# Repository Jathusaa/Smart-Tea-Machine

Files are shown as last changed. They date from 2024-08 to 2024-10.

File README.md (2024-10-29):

# Smart Tea Machine

This project features a Smart Tea Machine designed to automate the tea-making process. The machine includes various advanced features to enhance user experience:

## Features

- **Automatic Water Dispensing:** Dispenses the right amount of water for each cup of tea.
- **Tea Bag Dipping:** Dips the tea bag into the water to ensure optimal brewing.
- **Sugar Dispensing:** Automatically dispenses sugar according to user preferences.
- **Temperature Check:** Monitors the water temperature to ensure the perfect brewing conditions.
- **User Card System:** Utilizes RFID technology to recognize user preferences and customize the tea-making process.
- **User-Friendly Interface:** Designed for easy operation, featuring clear instructions and feedback.
- **Sound Alerts:** Equipped with a buzzer to alert the user when the tea is ready.

## Project Files

This repository includes the following files:

- **Arduino Code:** The main code for controlling the Smart Tea Machine.
- **PCB Files:** Design files for the printed circuit board (PCB) used in the machine.
- **Project Report:** A comprehensive PDF report explaining the design, functionality, and components of the Smart Tea Machine.

## Contributors

Thanks to the following team members for their contributions to this project:

- **[Jathusaa Indrakumaran](https://github.com/yourusername)** 
- **[Anisa Matan](https://github.com/Anisa-M1)** 
- **[Vishwa Prajapati](https://github.com/vishwapraja)**

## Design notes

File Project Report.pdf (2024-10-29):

## Smart Tea Machine Design Project Report

### ECE 2242

### Anisa Matan, Jathusaa Indrakumaran, Vishwa Prajapati

### Dr. Raveendra Rao

### April 2024

## Declaration Statement

We, the undersigned members of the group, collectively affirm that this report titled “Smart

Tea Machine Design Project Report” is our own joint work except where specifically

referenced. We take full responsibility for its accuracy and completeness.

Anisa Matan, Jathusaa Indrakumaran, Vishwa Prajapati

Date: April 7, 2024

## Acknowledgments

The team would like to express many thanks to everyone who helped create the Smart

Tea Machine. Special thanks to the individuals at the Western Electronics Shop

including Ron Struke, Eugen Porter, Trent Steensma and Robert Barbeito. Additional

appreciation is extended to the TAs of our lab section, Asad Hammed and Mayur

Sawant, as well as Professor Lyudmil Marinov and Professor Raveendra Rao for their

valuable assistance and support throughout the project.

## Table of Contents

## List of tables and figures

Fig. 1. Go-No-Go Chart | 7
Fig. 2. Comparison of Various Tea Machine Models by Tartar | 10
Fig. 3. Initial Block Diagram | 13
Fig. 4. Sketch of Prototype 1 | 15
Fig. 5. Sketch of Prototype 2 | 16
Fig. 6. Sketch of Prototype 3 | 16
Fig. 7. Final Block Diagram | 17
Fig. 8. Final Sketch of Prototype 1 | 18
Fig. 9. Tinkercad Circuit | 19
Fig. 10. Pseudocode | 20
Fig. 11. PCB Schematic Design | 21
Fig. 12. PCB Board Design | 21
Fig. 13. Soldered PCB Front and Back View | 23
Fig. 14. Finished Prototype Front and Back View | 24
Fig. 15. Finished Prototype Top and Side View | 24
Table 1: Sensors and Actuators Initially Used | 12
Table 2: Decision Matrix | 15
Table 3: Summary of Code Functions | 20

Abstract

This report details the design process in creating an Arduino operated automated tea

machine. The goal of this design project was to create an accessible appliance to automate a

common manual process for both homeowners and customers to save them time, reduce costs

and improve their user experience. By researching automated tea making machines currently

on the market, user needs, and the tea steeping process, the team was able to develop various

prototype ideas and set design objectives. The objectives of the Smart Tea Machine were

creating a user-friendly interface, dispensing water, sugar and tea to the user, and sensing water

level and temperature of the water used for steeping. After brainstorming multiple prototypes

ideas, the final design was chosen by taking durability, simplicity, cleanability, portability and

versatility into consideration. The prototype chosen employed five sensors, and four actuators

to achieve the objectives. Servo motors and a push button was used to dispense water and while

a DC motor and a push button was used to dispense sugar packets. Another servo motor was

used to dispense a tea bag into a cup of water. An LCD was used to communicate with the user,

and a buzzer was employed to notify the user when the tea steeping process was finished. A

water level sensor, and temperature sensor were also incorporated into the machine.

Additionally, a motion sensor was used to turn on the LCD when the user approached the

machine. Lastly, an RFID was also utilised to allow the machine to be used in commercial

settings. After simulating the circuit using Tinkercad, a PCB was designed and tested. The PCB

created was fully functioning and integrated with the mechanical design of the machine. Major

challenges of designing the Smart Tea Machine include the implementation of the RFID and

the water dispensing mechanism. Future improvements include making the design more

versatile to accommodate for wider varieties of tea and improving the mechanisms used to

dispense various ingredients. In conclusion, the project was successful overall, and all design

objectives were achieved.

### 1. Introduction

Despite developments in both household and commercial appliances in the modern age,

homeowners and customers alike still require more accessible and automated appliances for

common manual processes to save time, reduce costs, and improve user experience. Many

processes that are still manually done have not yet been refined and been made accessible to a

wide variety of users. This design project aimed to automate one such process for both

customers and homeowners. After thorough research into various processes that could benefit

from automated refinement and taking into consideration project requirements, the tea making

process was decided upon by weighing pros and cons of all brainstormed ideas with the use of

a Go-No-Go Chart as seen in Figure 1 and the “Idea Development” section of the design

notebook listed in the appendices.

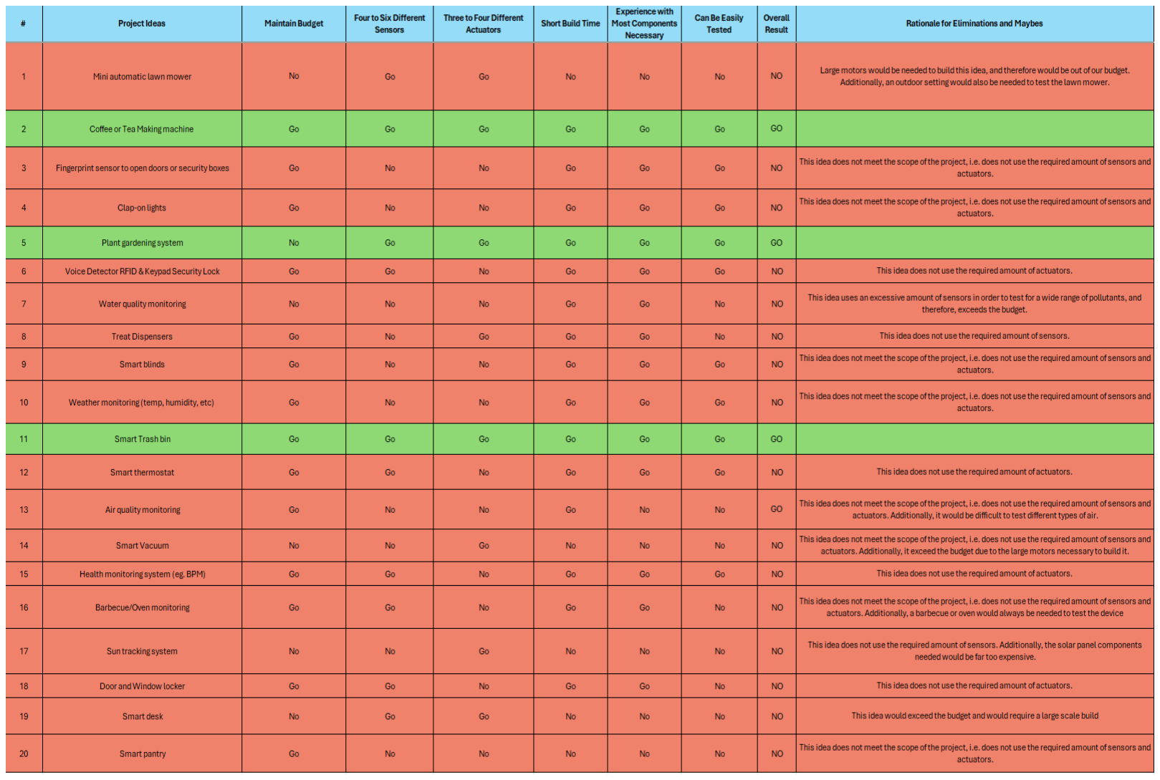
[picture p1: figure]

Fig. 1. Go-No-Go Chart Outlining if project constraints are met by various ideas

The tea making process could be improved for any individual by prioritizing

convenience and cost efficiency. While tea making machines are currently available on the

market, the lack of popularity is driven by high prices and lack of customization for creating

different types of tea. For example, the Breville One-Touch Tea Maker is one of the few tea

machines on the market that fully automates the tea making process in a similar fashion to a

coffee machine and retails for upwards of $200 [1]. Both tea enthusiasts and casual tea drinkers

need a higher quality and cheaper alternative to machines currently on the market. The tea

making process can also be difficult for individuals with disabilities due to the manual nature

of the process. Moreover, automating the process would facilitate making tea for individuals

with less experience as a machine would ensure consistency in temperature, water level, and

flavour. This design project aimed to specifically automate the process by:

- Creating an LCD user friendly interface
- Sensing temperature and water level of water required for tea making
- Dispensing water to the user
- Dispensing tea into water (either in the form of a tea bag or loose leaves)
- Dispensing sugar to the user

With these objectives in mind, a smart tea machine was created with the intention of

practical applications in various places like homes, offices, workplaces, restaurants, cafes,

healthcare facilities, events, and catering.

### 2. Literature Review

The literature review consisted of researching the tea steeping processes and various

tea making products currently on the market to better understand the needs of users. Tea

brewing refers to the general process in making tea, while steeping is the process of immersing

tea leaves in water. These findings aided in the development of initial prototypes and helping

to outline the objectives of the machine listed above.

A study done by Katherine Ann Tartar at MIT called “Simplifying Tea Steeping:

Design Innovation Driven by User Needs" succinctly summarizes the current automated tea

machine models, steeping methods and proposed alternatives [2]. Tartar conducted a survey of

235 individuals in the ages of 18 to 27 to determine their preferences in the tea making process.

She found that most user preferred tea bag over loose-leaf steeping due to the inherent

messiness of the process using a strainer. This insight prompted further research into the

differences between tea bag and loose-leaf steeping, revealing three key differences [3]:

- Tea bags are made from low quality, cheaper leaves that have been pulverized down

to tiny pieces, while loose leaves are whole, therefore, providing stronger flavour

- As the tea steeps, loose leaves are able to expand more and unravel to release flavour

while tea bags are tightly packed restricting flavour, but taking less time to brew

- Both tea bag and loose-leaf steeping require hot water, while loose leaves

additionally require a device to infuse the leaf flavour into the water, which can be

simple paper filters, tea pots, or strainers.

Tartar’s study also outlined the top features that the individuals surveyed would want

in a tea machine, which include water temperature testing, timing, removal of tea leaves,

portability, simplicity and cleanability. Another important piece of information from Tartar is

the comparison of various tea machine currently on the market and their short falls as seen in

the Figure 2. This comparison helped the team brainstorm prototypes that address the

shortcomings of current automated tea making options.

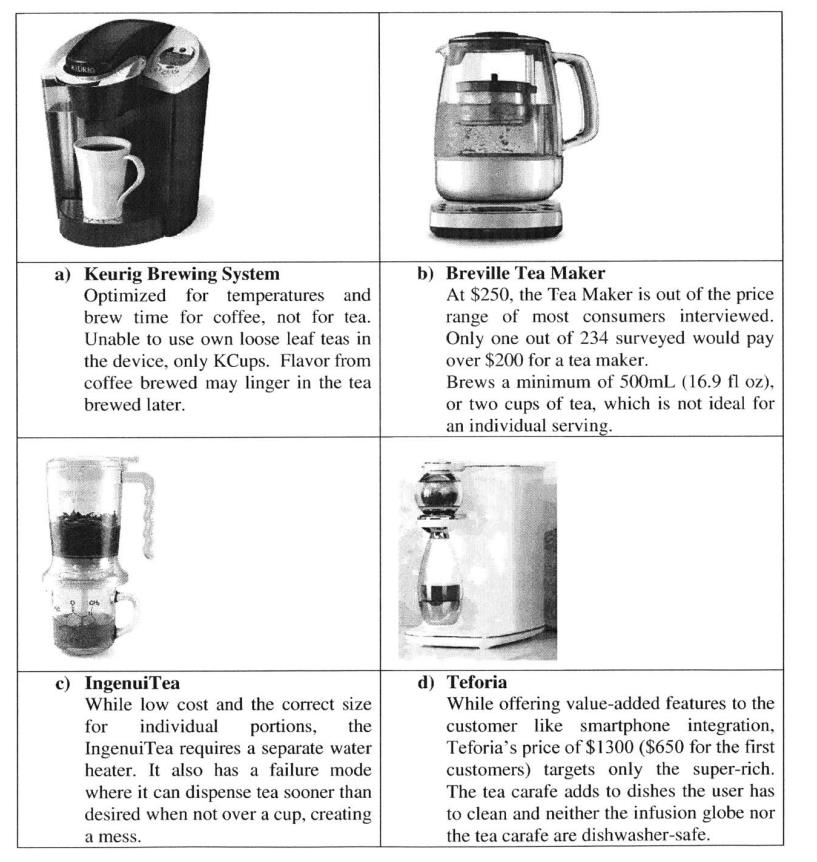
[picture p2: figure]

Fig. 2. A chart by Tartar highlighting various tea making machine currently on the market [2]

Lastly, research was done into cold vs hot water tea steeping to determine which would

be more effective in steeping the tea in the machine. According to research by Lantano et al.,

cold water steeping is most effective in extracting healthy molecules like antioxidants, while

hot steeping was faster but and extracted more flavour [4]. The study also considered an

emerging method which involved hot steeping and then adding ice to the tea. This information

was taken account when deciding the steeping method and water temperature used in the tea

making process.

### 3. Design Constraints and Standards

There were three major design constraints outlined at the beginning of the course:

- The final product must contain four to six sensors
- It must contain three to four actuators
- The software must work simultaneously with all components

Other design constraints determined by the team were pertaining to the budget, build

time, and testability. The team determined that the budget would not exceed $100 excluding

the $50 cost of the Arduino kit. The project selected also had to have a short build time allow

for debugging and successful function by the early April deadline. Furthermore, the project

selected would need to be tested easily. Projects that were eliminated were often difficult to

test due to their costly and time-inefficient nature. For example, a water quality monitoring

system that was considered in Figure 1 would require the purchasing of various unique sensors

and simulation of polluted water. Lastly, the team decided that the project chosen should not

require the use of too many (more than 3) components that the members did not have

experience working with.

### 4. Design

Based on the objectives of the machine, initially the team decided to use the

components summarized in table 1 below.

Table 1: Sensors and Actuators Initially used in the Smart Tea Machine

Type | Component | Signal | Quantity | Purpose
Sensor | Temperature sensor | Digital | 1 | Detects temperature of water being used to make tea
| Water level sensor | Analog | 1 | Detect how much water is needed to make tea
| Motion sensor | Digital | 1 | Detects when user wants to turn on machine
| Push button | Digital | 2 | Allows user to dispense water or sugar
| RTC | Digital | 1 | Times the process
| RFID | Digital | 1 | Allows user to earn discounts in a commercial setting
Actuator | Servo Motor | Digital | 2 | Dispenses water and tea bag in cup as well as sugar if it is uncontained
| Stepper Motor | Digital | 1 | To help dispense sugar if in the form of packets
| LCD | Digital | 1 | Displays instructions to user and narrates process
| Buzzer | Digital | 1 | Notifies user when tea making process is finished

The block diagram in Figure 3 was developed based on the table above which outlines

the inputs and outputs in relation to the Arduino.

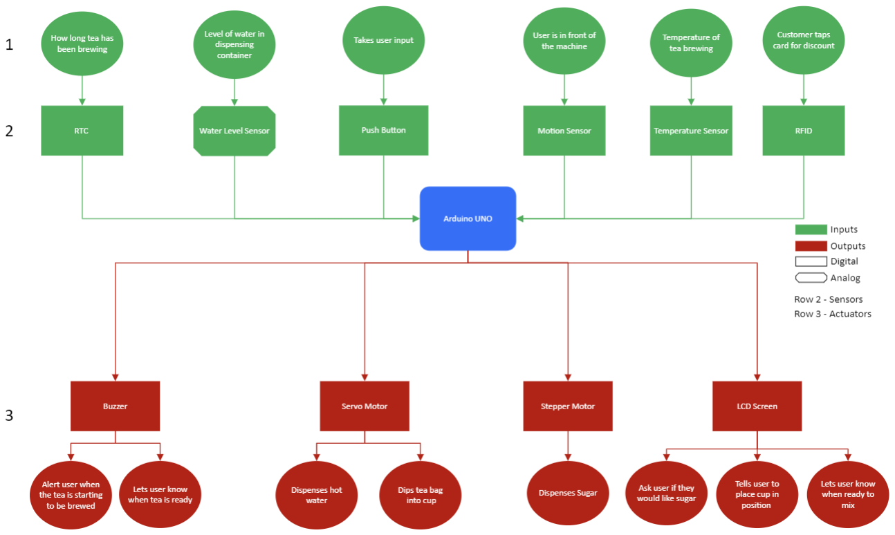
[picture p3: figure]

Fig. 3. The initial block diagram with RTC and stepper motor

Choosing a Prototype

Using the insights gained in the literature review, various prototypes ideas were generated

and decided upon using a decision matrix as seen in Table 2. The three prototype ideas were

developed, two of which used a tea bag while one used loose leaves. The team considered

creating prototype designs using both loose leaves and tea bags, however decided to focus on

tea bags as it would be more time-efficient for users. Additionally, it was decided that the

prototype were to be constructed out of recyclable materials to reduce costs. The attributes used

to rank the alternatives were based on the customer needs explored in the literature review and

the team’s priorities.

The metrics used to rank the prototype were as follows:

1. Simplicity: Is the prototype easy to operate, in other words, is it user friendly?
2. Cleanability: Does the prototype leave excessive waste for the user to clean up

afterwards?

3. Durability: Is the machine prone to damage or breaking?
4. Versatility: Does it allow the brewing of various types of tea?
5. Portability: Is the machine easy to move around?

The metrics had different weighting depending on how important they were to the team’s

objectives, as shown by the order in which they appear above. The weights were on a scale of

1 to 5. Each prototype idea was ranked on a scale of 1 to 10 in each of the categories and total

scores were added up.

There was also qualitative analysis that was considered in choosing each prototype.

Prototype 1, as seen in Figure 4, was the most compact and simple alternative but was lacking

full integration of the tea dipping mechanism into the machine. Additionally, dispensing

packets of sugar would be better suited for a commercial setting, while being less convenient

for a homeowner. Seen in Figure 5, Prototype 2 would be more ideal for tea enthusiasts rather

than casual tea drinkers due to the use of loose tea leaves. Furthermore, avid tea drinkers are

likely unconcerned with automated tea making, as they would be more willing to use traditional

methods to make quality tea. The team aimed to make the tea making process more accessible

for individuals who want to save time, so this eliminated the second prototype as an option.

Moreover, Prototype 2 would not be able to accommodate the amount of water needed to steep

the tea leaves. Lastly, Prototype 3, as seen in Figure 6, was more compact than Prototype 1 but

clustered many of components into a small area, making it non-user friendly and more difficult

to construct. There was also the use of the tube to direct the tea to the cup, making the design

prone to damage and leaking. Prototype 3 also use sugar that was uncontained, making it a

messy alternative. All prototypes ranked the same in the category of versatility as they could

only accommodate one type of tea steeping. Considering the result of the decision matrix and

qualitative factors, the team decided Prototype 1 was the best alternative as it ranked the highest

and met user needs the best.

Table 2: Decision Matrix Evaluating Prototypes

Metrics | Weight | Prototype 1 | Prototype 2 | Prototype 3
Simplicity | 5 | 8 | 5 | 6
Cleanability | 4 | 9 | 6 | 8
Durability | 3 | 7 | 6 | 4
Versatility | 2 | 5 | 5 | 5
Portability | 1 | 8 | 5 | 8
Total Score | | 115 | 82 | 92

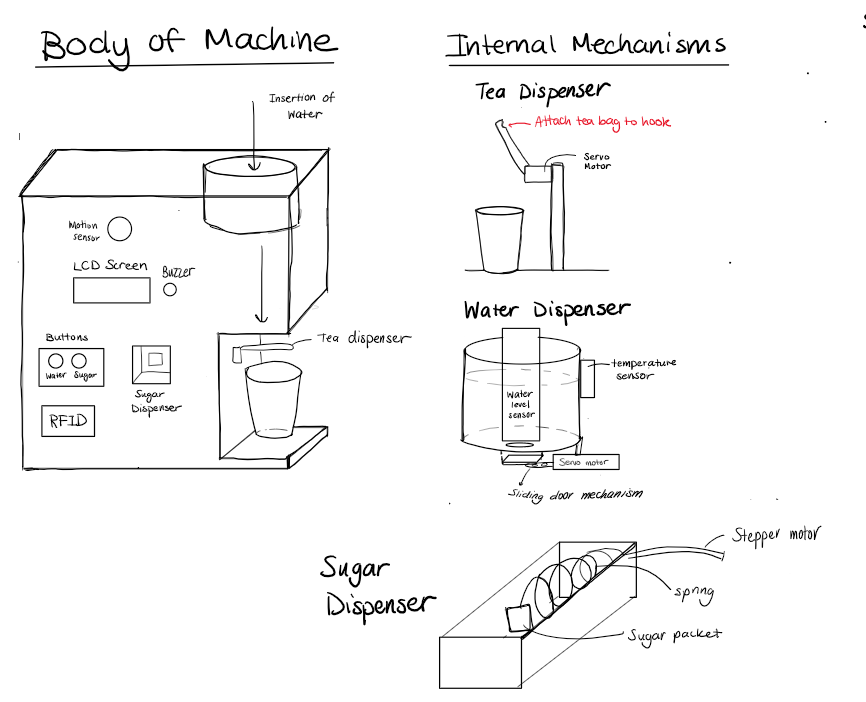
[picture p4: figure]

Fig. 4. Preliminary sketch of Prototype 1

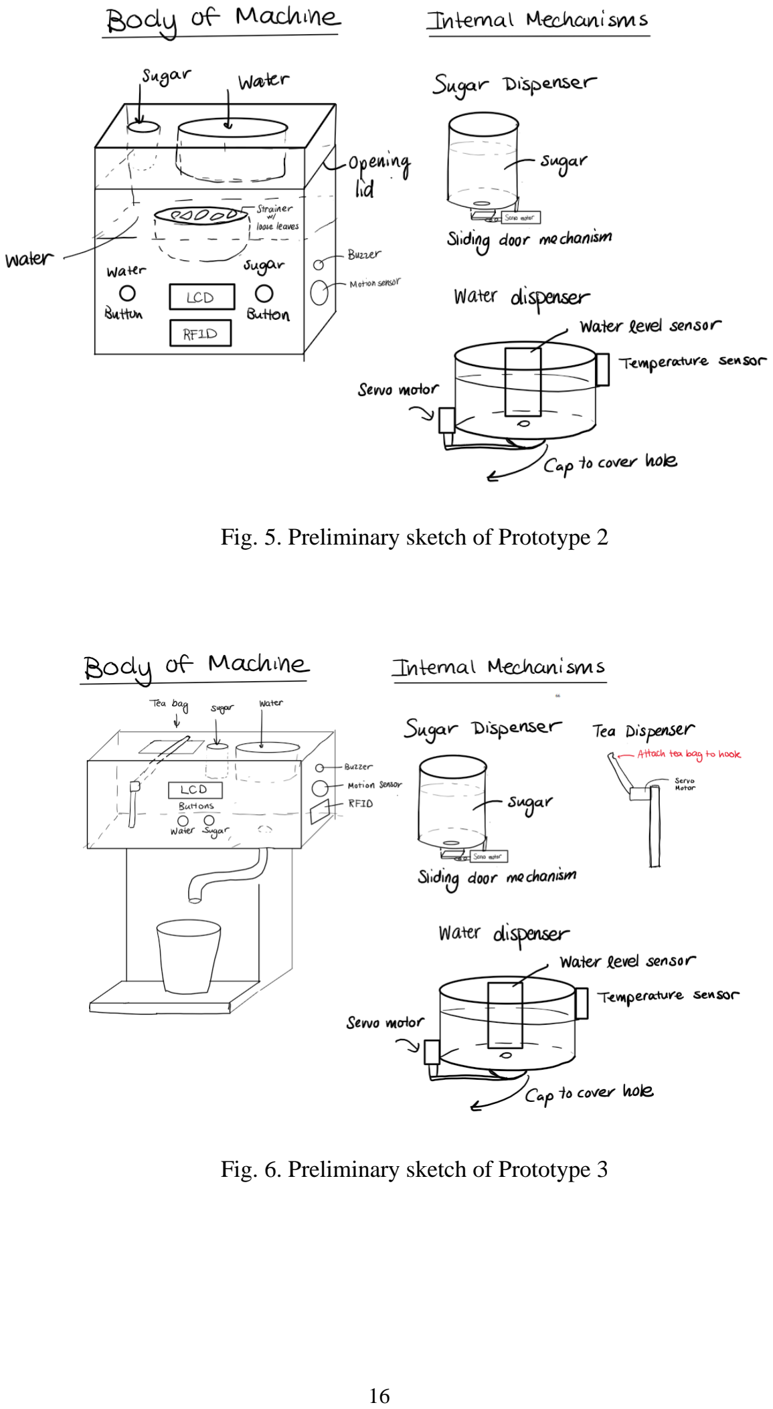
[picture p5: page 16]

Fig. 5. Preliminary sketch of Prototype 2

Fig. 6. Preliminary sketch of Prototype 3

Final Block Diagram and Sketch

After the final prototype was decided upon, the team was able to refine the initial block

diagram into the final one seen in Figure 7. The team decided to use a DC motor instead of

stepper motor due to previous experience with DC motors and access to one. Additionally, the

RTC component was eliminated as the Arduino has a built-in timing function that was simpler

to code and implement.

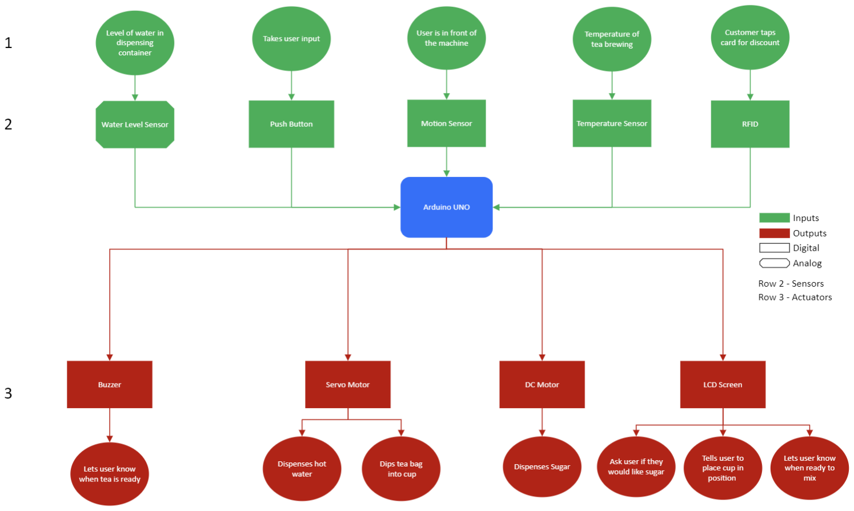
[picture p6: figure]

Fig. 7. Final block diagram showing all sensors and actuators that were used in final

prototype

A final sketch of the prototype was also created with dimensions and all final features,

as seen in Figure 8.

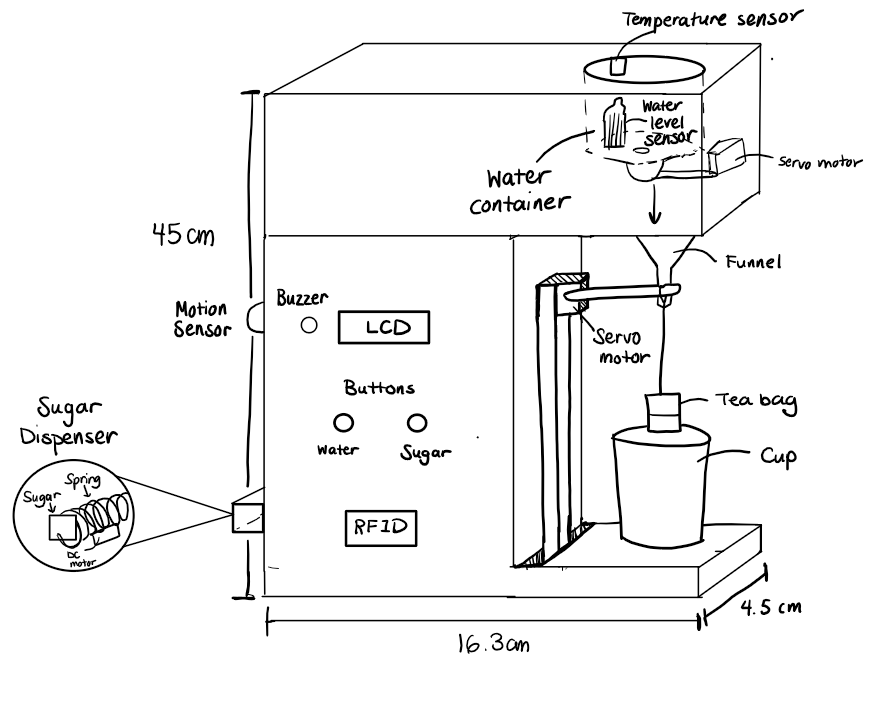
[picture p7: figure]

Fig. 8. Final sketch of the chosen prototype with dimensions and the placement of all

sensors and actuators

Tinkercad Design

After the block diagram was built, the team got started on building the circuit through

the circuit simulation website called Tinkercad. The Tinkercad library contained most of the

components in the project, however some specific ones were not available. The components

that were not available were the RFID, DHT11 Temperature Sensor and water level sensor. As

seen in the diagram in Figure 9 below, the water level sensor was replaced by the potentiometer,

and the DHT11 was substituted with the TMP36 for the simulation. The Tinkercad simulation

can be accessed through this public link: Tinkercad Link. (https://www.tinkercad.com/things/cgkHrHxIvF2-ece-2242-project-tinkercad-project-final/editel)

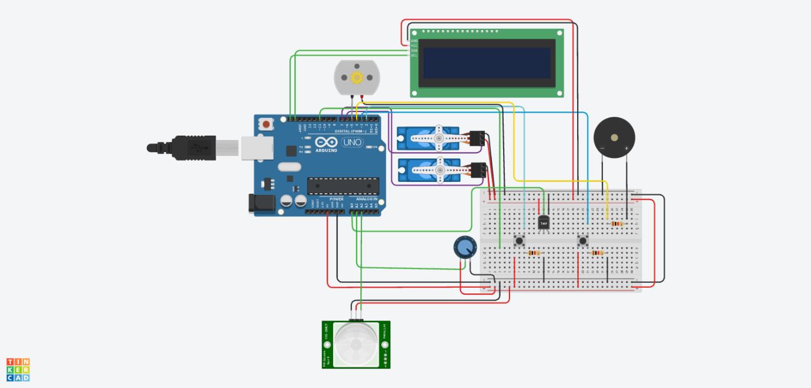
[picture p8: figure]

Fig. 9. Circuit built on Tinkercad

Software Development

To make sure the components of the machine were functional, the team got started on

programming the Arduino while working on the Tinkercad prototype. Through the circuit

simulation on Tinkercad, the prototype’s program was shown to be operational as the electronic

components worked together as intended. The final program was modified as Tinkercad did

not include certain electronic components. The code for the Arduino’s program can be found

in this file: FINAL_code.ino. (https://uwoca-my.sharepoint.com/:u:/g/personal/jindrak2_uwo_ca/Ebjy4fLpXNJIpqjShvW2FvgB_XvsIJcH5wVyikv8JVeTSQ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)

The program starts with calling the necessary libraries for controlling components such

as servo motors, LCD, DHT temperature sensor, RFID, and MFRC522 for RFID

communication. It then defines the pin connections for various components that are used in the

machine. Once the pin connections are defined, the program moves onto the setup function in

which components such as the LCD display, servo motors, buzzer, DC motor, RFID and the

buttons are initialized. Serial monitor communication is also programmed in this part of the

code for testing purposes. Following the setup, the program enters the loop function, where the

majority of the machine's algorithm runs. Within the loop function, other functions are called

to perform specific tasks as displayed through pseudocode in Figure 9. Table 3 breaks down

each function’s purpose.

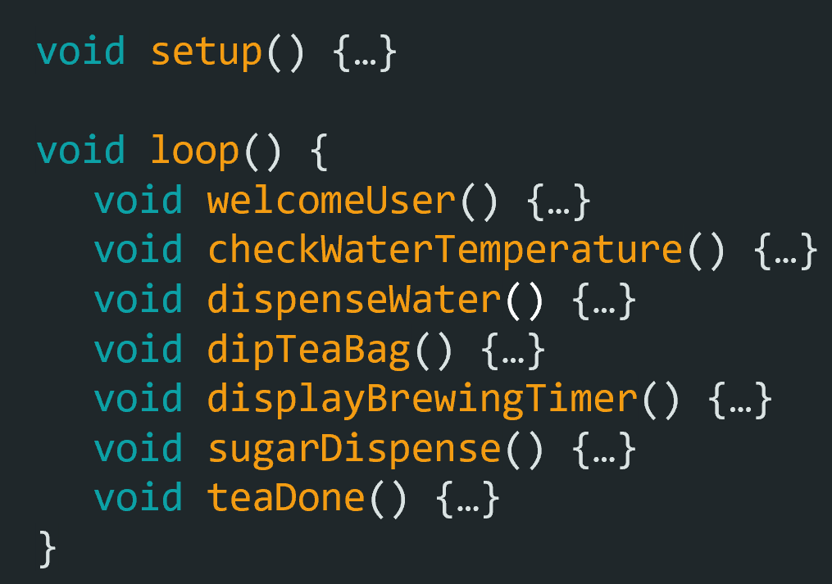
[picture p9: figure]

Fig. 10. Pseudocode outlining the major functions in the final code in the Arduino IDE

Table 3: Functions used in Arduino Code and Their Purposes

Function | Purpose
welcomeUser() | Displays a welcome message when the user approaches the machine.
checkWaterTemperature() | Checks the water temperature and prompts the user to replace or add hot water if it is not at the desired temperature.
dispenseWater() | Dispenses water until the water level reaches a certain threshold.
dipTeaBag() | Dips a tea bag into the water for brewing.
displayBrewingTimer() | Displays a timer for the tea brewing process.
sugarDispense() | Dispenses sugar using a DC motor.
teaDone() | Indicates when the tea-making process is completed and prompts the user to scan an RFID card for points

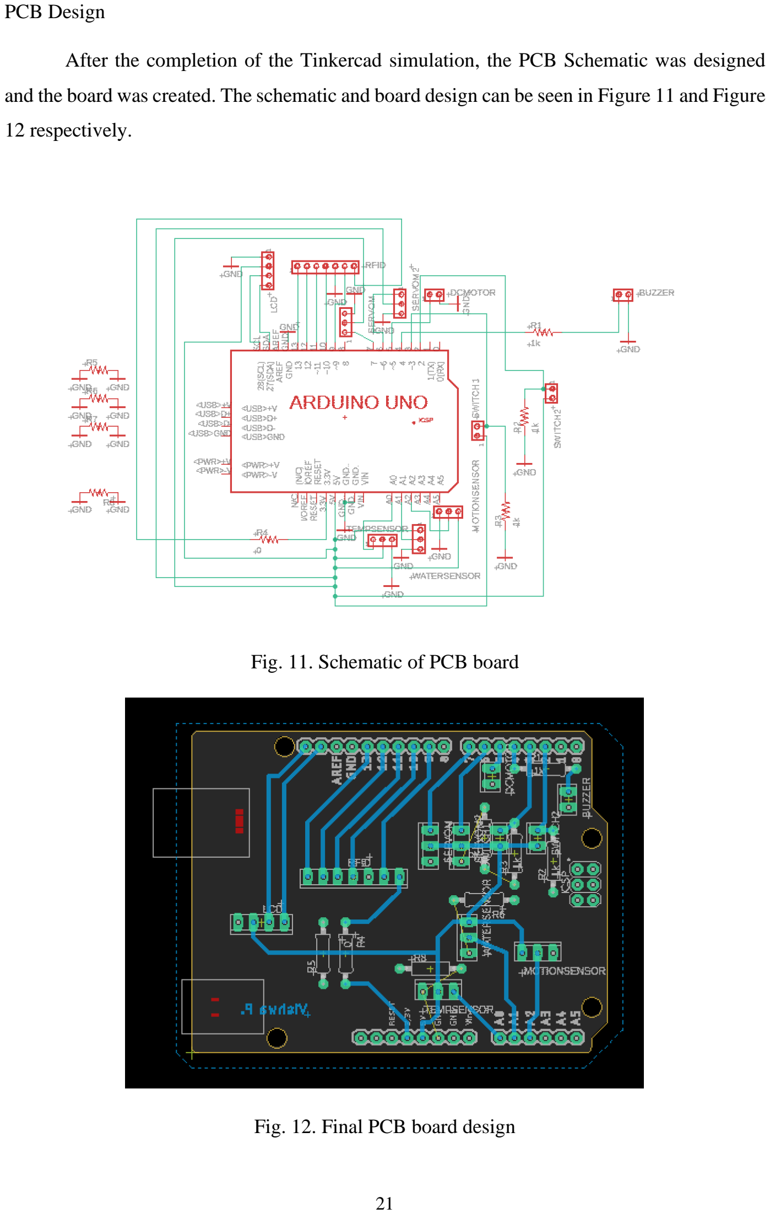
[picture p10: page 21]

PCB Design

After the completion of the Tinkercad simulation, the PCB Schematic was designed

and the board was created. The schematic and board design can be seen in Figure 11 and Figure

12 respectively.

Fig. 11. Schematic of PCB board

Fig. 12. Final PCB board design

### 5. Implementation

Technical Testing and Debugging

The prototype was tested in multiple phases. The first testing that was done was using

a breadboard. The code was tested without the physical mechanisms in place (as seen here). (https://www.youtube.com/watch?v=w1fYX33rKzU&feature=youtu.be)

All electronic components were functional except the temperature sensor. The temperature

sensor displayed an incorrect temperature due to improper connection on the breadboard. After

this error was fixed, the temperature sensor was able to function properly.

The RFID was not tested with the breadboard due to problems integrating its code with

the entire process. When the RFID code was placed at the beginning of the execution, it did

not allow any other sensors to operate. After some trial and error, it was discovered that placing

the RFID code after all other sensors had finished their operations would allow the process to

work.

When the mechanical components were finished, the two servo motor-based

mechanisms were tested so that the angles of motion could be confirmed. The tea dipping

mechanism functioned properly (as seen here) (https://www.youtube.com/shorts/IkBxaQKHlNU) while the water dispensing mechanism was not

able to hold water in the container until water was supposed to be dispensed. Alternative

methods were proposed to solve the water dispensing problem such as using a rubber sealed

cap, a bigger cap, or a plug. The first two methods proved unsuccessful due to water spewing

from the edges of the cap, so the plugging method was utilized. The plugging method did not

fully eliminate the leakage however, reduced it to drips. The two mechanisms can be seen in

the videos linked below:

a. Initial water dispenser mechanism with significant leakage (https://www.youtube.com/shorts/gKbsbAijxiE)
b. Final water dispenser mechanism with minimal leakage (https://www.youtube.com/shorts/gF-5kCV_DJY)

Afterwards, the PCB was soldered and each component was tested separately with

generic code. During this phase of testing the RFID and LCD did not work due to short circuits

created during soldering. These problems were fixed by checking the connectivity of all

components and resoldering them in the lab. The PCB was tested with all components on

It and the tea process code after this issue was solved as seen in this video. (https://www.youtube.com/watch?v=rcWSlyimBmU&ab_channel=VishwaPrajapati) Figure 13 shows

the fully soldered PCB from the front and back.

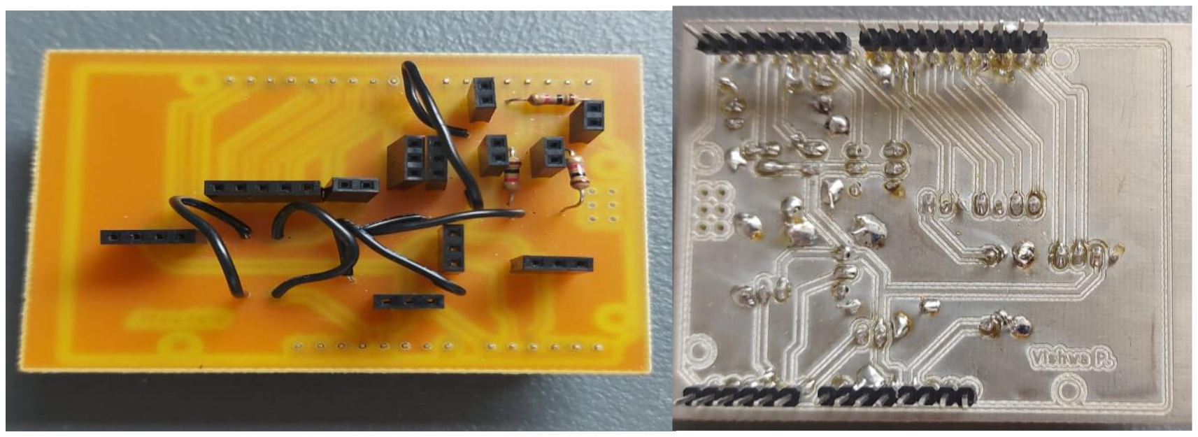
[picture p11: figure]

Fig. 13. Front and back view of fully soldered PCB

Another obstacle that was faced was the use of hot water in the machine. While cold

steeping methods were researched, the team decided to use hot water as it is the most common

method of preparing tea. Additionally, the temperature sensor used could not be immersed in

water, and therefore would be able to sense the heat from steam more easily. However, since

the plug of the water dispensing method was secured with hot glue, and it was in contact with

hot water in the dispensing container, the plug became unattached to the servo arm

occasionally. Due to this, cooler water was used to test and demonstrate prototype.

Lastly, the components were placed in the body of the machine and the Smart Tea

Machine was able to function according to plan. Images of the final prototype from multiple

views can be seen in Figures 14 and 15.

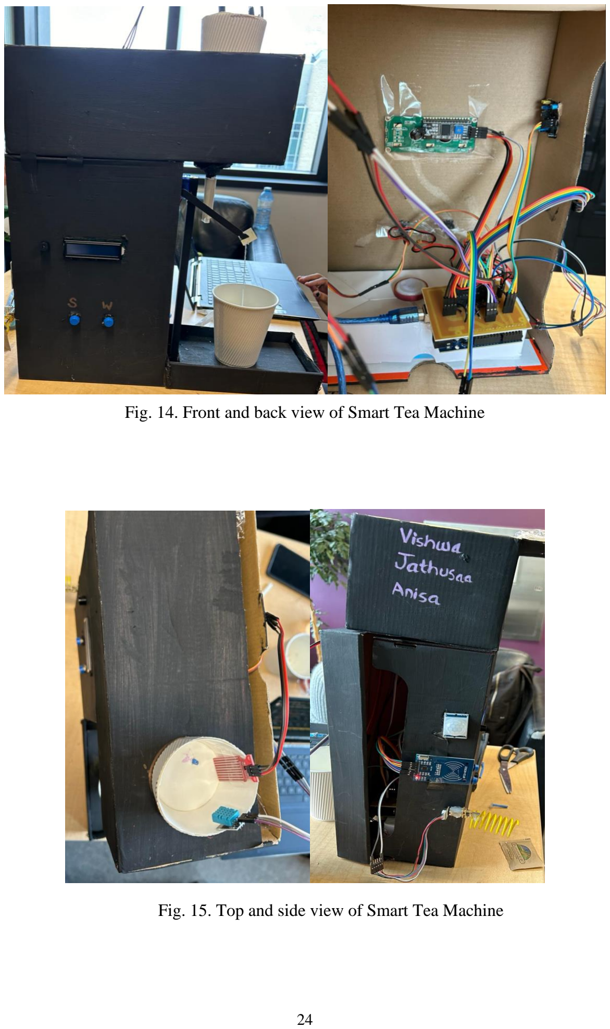
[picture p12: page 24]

Fig. 14. Front and back view of Smart Tea Machine

Fig 15: Top and bottom view of Smart Tea Machine

Fig. 15. Top and side view of Smart Tea Machine

A user manual outline was also created to facilitate the operation of the machine. This

can be seen below:

User Manual

Introduction: The Smart Tea Machine is a portable device designed to brew tea conveniently.

Powered by a 9 V battery, this machine offers flexibility and ease of use wherever you go.

This user manual will guide you through the setup and operation of the Smart Tea Machine.

Setup:

1. Ensure the Smart Tea Machine is placed on a stable surface.
2. Insert a fully charged 9 V battery into the designated battery compartment.
3. Make sure the water container is filled with hot water.
4. Hook the tea bag onto the brewing tea stand
5. Place your cup or mug in the designated position

Operation

1. Stand in front of the machine to activate the motion sensor
2. Follow the on-screen instructions to start the tea making process
3. Press the corresponding buttons to dispense water, the tea bag, and a sugar packet
4. Follow the LCD screen prompts for guidance.
5. Wait for the tea making process to be complete as signified by the buzzer
6. Once the tea is done, remove your cup or mug from the machine and enjoy your

freshly brewed tea

Maintenance:

1. After each use, ensure all components of the machine are cleaned and dried

thoroughly.

2. Regularly check the battery and replace it as needed to ensure uninterrupted

operation.

Safety Precautions

1. Do not immerse the Smart Tea Machine in water or any other liquid.
2. Avoid using the machine if it shows any signs of damage or malfunction.

Cost Analysis

The cost to build the Smart Tea Machine was minimal as the body of the machine was

constructed from recyclable and reused materials, like carboard. Two items were bought online

to make the machine: A pack of 9 V batteries to make the machine portable, and extra wires to

facilitate the connection of the components to the PCB ($15 total). Considering the cost of the

Arduino kit at $50, the total cost of the constructing the Smart Tea Machine was $65 dollars.

The price indicates that the machine is a more cost effective alternative to the tea machines

currently on the market like the Breville One-Touch Tea Maker.

### 5. Results and Evaluation

The tea machine worked as intended. All the sensors and actuators worked to achieve

their objectives. This video (https://www.youtube.com/watch?v=JnMQlZM-Gls) shows the working of the whole tea machine. In the video’s

description, timestamps have been added for all the 11 components of the whole machine. This

other video (https://youtu.be/Da2STaleuy0) shows the LCD screen clearly throughout the whole process. The serial Monitor (https://youtu.be/SBoqBV6Y1s4)

during the entire process was also recorded in the video linked. This was a success as all the

components work together on the PCB.

During the process, the main challenge was the RFID as it was a new component.

However, through trial and error, RFID implementation was successfully done. The LCD was

not fully functional earlier in the process, but the issue was resolved later by resoldering the

ground connection. The water dispensing mechanism required more attention due to leakage,

however it was ultimately minimal and did not majorly affect the machine’s operation.

The mechanical component of the machine was the main weakness. Since the machine

was made from cardboard, the water easily wetted the box and the water leaked occasionally.

Despite these challenges, the water leakage was managed well. Leakage was mitigated by

creating a plastic shield over cardboard in contact with the water. In conclusion, all objectives

set out at the beginning of the project were achieved.

### 7. Future Work

In terms of further improvements, several areas were identified:

Firstly, there is a need to ensure the water dispensing mechanism is more reliable. There

was slight leakage and malfunction during the dispensing process. This could be prevented by

using a stronger servo motor which could significantly enhance the reliability of the dispensing

and allow a more watertight plug. Secondly, in the future the program could be refined to

incorporate error detection in case a user accidently presses the wrong button. Implementing

such a feature would improve the user’s experience by providing clear feedback and guidance,

reducing the likelihood of mistakes.

Other improvements:

- Enhancing the integration of the tea dipping mechanism
- Expanding the capacity to accommodate larger tea servings
- Providing users with the option to select their desired steeping time in order to

facilitate the brewing of a wide variety of teas

To further development the machine, attention could be given to enhancing the user interface

with more detailed features. Furthermore, exploring the use of alternative materials that are

easier to clean and offer greater durability may contribute to the overall reliability and longevity

of the machine.

### 8. Conclusion

In conclusion, the Smart Tea Machine design project has successfully achieved its

objectives of automating the tea making process to provide users with a convenient solution to

manually brewing tea. With thorough research, detailed design considerations and repeated

testing, the team has developed a functional prototype that effectively dispenses water, tea and

sugar while monitoring temperature and water level, and providing a user-friendly interaction

through an LCD interface. Despite encountering challenges such as integrating the RFID

system and ensuring reliable water dispensing, the team demonstrated strength and problem-

solving skills to overcome such obstacles. For further improvement, refinements and

enhancements can be made to improve reliability of the machine and user experience. Overall,

the Smart Tea Machine has transformed tea preparation into a seamless and delightful

experience.

References

[1] D. Schwartz, “I’m Spilling the Tea on My ‘Groundbreaking’ Kettle (That’s As Smart

As They Get)”, New York Magazine. Accessed: April 06, 2024. [Online]. Available:

https://nymag.com/strategist/article/breville-one-touch-tea-maker-review.html.

[2] K. Tartar, “Simplifying Tea Steeping: Design Innovation Driven by User Need”, Jun.

2016. [Online]. Available:

https://dspace.mit.edu/bitstream/handle/1721.1/105665/964446803-

MIT.pdf?sequence=1&isAllowed=y. (https://dspace.mit.edu/bitstream/handle/1721.1/105665/964446803-MIT.pdf?sequence=1&isAllowed=y)

[3] “Loose Leaf Tea vs. Tea Bags: What's the Difference?” Artful Tea. Accessed: April

06, 2024. [Online]. Available: https://artfultea.com/blogs/tea-wisdom/loose-leaf-vs-

tea-bag. (https://artfultea.com/blogs/tea-wisdom/loose-leaf-vs-tea-bag)

[4] C. Lantano, M. Rinaldi, A. Cavazza, D. Barbanti, and C. Corradini, “Effects of

alternative steeping methods on composition, antioxidant property and colour of

green, black and oolong tea infusions,” Journal of Food Science and Technology, vol.

52, no. 12, pp. 8276–8283, Dec. 2015, doi: 10.1007/s13197-015-1971-4. (https://doi.org/10.1007/s13197-015-1971-4)

Appendices

1. Link to design notebook: Design Notebook (ECE 2242).docx (https://uwoca.sharepoint.com/:w:/s/ECE2242LabGroup/EdoBBep2wqlFpXANjy_kdxwBhMEnYUNKH8KtLatB0PHkTg)
- Note: Please view in app rather than web for clear formatting (Go to editing in top right corner and select view in desktop app)
2. Link to teams channel documents: https://uwoca.sharepoint.com/:f:/s/ECE2242LabGroup/Ek_GqaFCl2RLhGjxQ7tvYxIBbbEJc3fnpIbrN0Wsf2liEQ?e=ldOM8C (https://uwoca.sharepoint.com/:f:/s/ECE2242LabGroup/Ek_GqaFCl2RLhGjxQ7tvYxIBbbEJc3fnpIbrN0Wsf2liEQ?e=ldOM8C)

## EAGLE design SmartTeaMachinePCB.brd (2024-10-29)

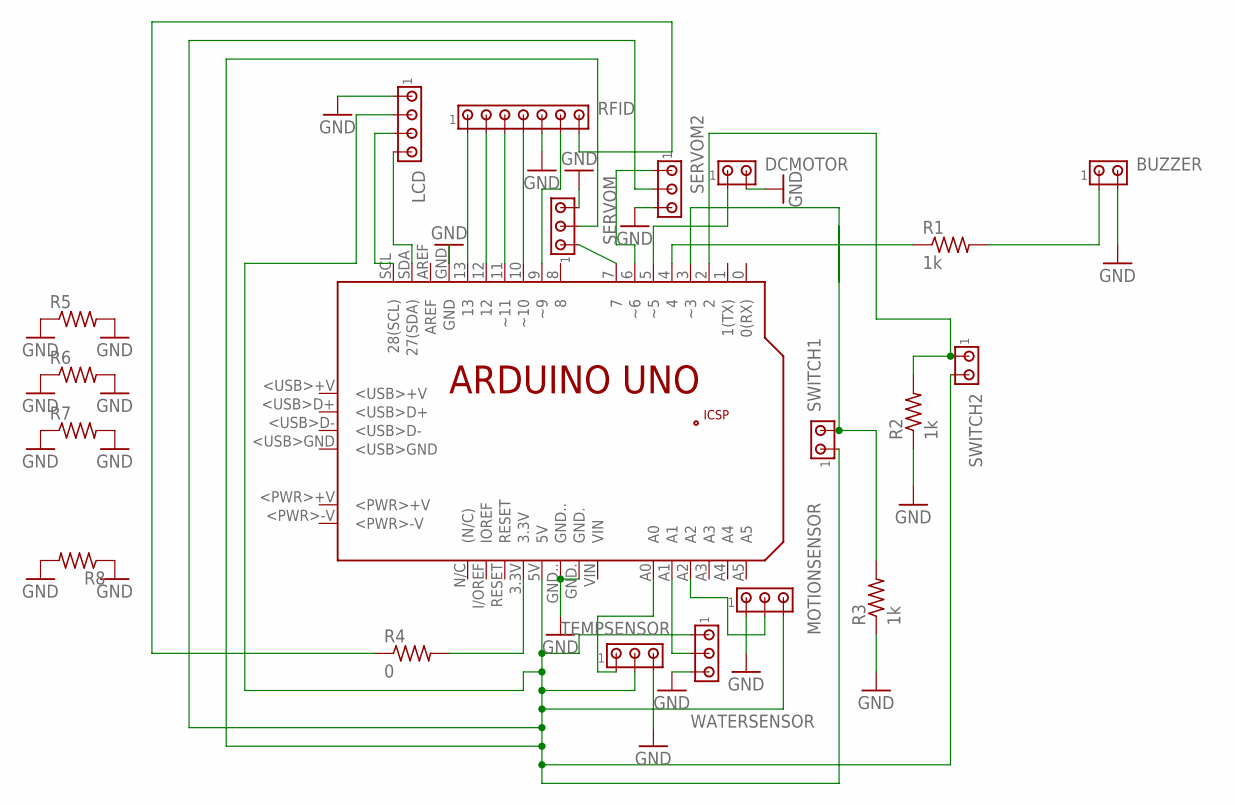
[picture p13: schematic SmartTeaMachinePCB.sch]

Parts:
BUZZER: MTA02-100; 10X02MTA
DCMOTOR: MTA02-100; 10X02MTA
LCD: MTA04-100; 10X04MTA
MOTIONSENSOR: MTA03-100; 10X03MTA
PCB1: ARDUINO_UNO
R1, R2, R3: 1k; 0207/10
R4: 0; 0207/10
R5, R6, R7, R8: R-US_0207/10; 0207/10
RFID: MTA07-100; 10X07MTA
SERVOM, SERVOM2: MTA03-100; 10X03MTA
SWITCH1, SWITCH2: MTA02-100; 10X02MTA
TEMPSENSOR: MTA03-100; 10X03MTA
WATERSENSOR: MTA03-100; 10X03MTA

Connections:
GND: BUZZER.2, DCMOTOR.2, LCD.1, MOTIONSENSOR.1, PCB1.GND, PCB1.GND., PCB1.GND.., R2.1, R3.1, R5.1, R5.2, R6.1, R6.2, R7.1, R7.2, R8.1, R8.2, RFID.5, SERVOM.3, SERVOM2.3, TEMPSENSOR.3, WATERSENSOR.3
unnamed: PCB1.7, SERVOM.1
unnamed: PCB1.6 (~6), SERVOM2.1
unnamed: PCB1.A1, WATERSENSOR.2
unnamed: PCB1.A0, TEMPSENSOR.1
unnamed: LCD.2, MOTIONSENSOR.3, PCB1.5V, SERVOM.2, SERVOM2.2, SWITCH1.1, SWITCH2.2, TEMPSENSOR.2, WATERSENSOR.1
unnamed: LCD.3, PCB1.SCL (28(SCL))
unnamed: LCD.4, PCB1.SDA (27(SDA))
unnamed: PCB1.13, RFID.1
unnamed: PCB1.12, RFID.2
unnamed: MOTIONSENSOR.2, PCB1.A2
unnamed: PCB1.11 (~11), RFID.3
unnamed: PCB1.10 (~10), RFID.4
unnamed: PCB1.9 (~9), RFID.6
unnamed: R4.1, RFID.7
unnamed: DCMOTOR.1, PCB1.5 (~5)
unnamed: PCB1.4, R1.1
unnamed: BUZZER.1, R1.2
unnamed: PCB1.2, R2.2, SWITCH2.1
unnamed: PCB1.3.3V, R4.2
unnamed: PCB1.3 (~3), R3.2, SWITCH1.2

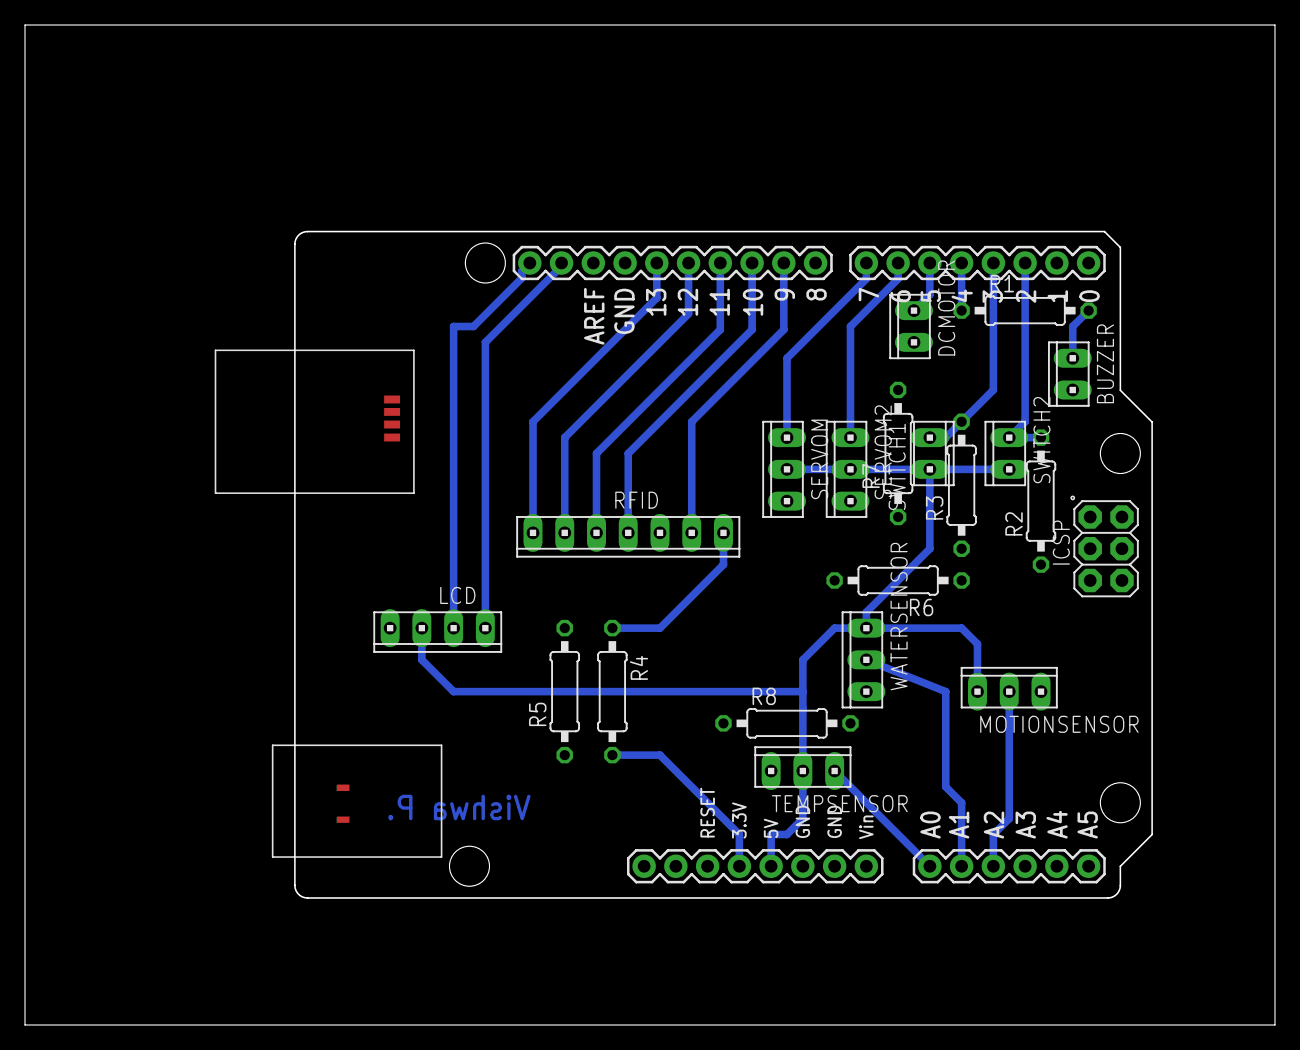
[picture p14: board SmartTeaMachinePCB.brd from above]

Board: 2 copper layers, 100.0 x 80.0 mm, 20 parts (0 on the bottom side), 21 nets.

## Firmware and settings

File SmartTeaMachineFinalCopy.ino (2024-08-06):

/*
  This is a Smart Tea Machine code written for an Arduino.
  It automates the process of making tea, including dispensing water,
  dipping a tea bag, dispensing sugar, and alerting the user when the tea is ready.
*/

// Libraries
#include <Servo.h> // Library for controlling servo motors
#include <LiquidCrystal_I2C.h> // Library for I2C LCD
#include <Wire.h> // Library for I2C communication
#include <dht.h> // Library for DHT temperature and humidity sensor

// Object instantiation
dht DHT; // DHT sensor object
Servo waterservo; // Servo motor for water dispensing
Servo teaservo; // Servo motor for dipping tea bag
LiquidCrystal_I2C lcd_1(0x27, 16, 2); // LCD object

// Variables initialization
int pos = 0; // Position for water servo motor
int pos2 = 0; // Position for tea servo motor
int count = 0; // Counter for tea dipping (for testing)
int count1 = 0; // Counter for water dispensing (for testing)
#define DHT11_PIN A0 // Pin for DHT sensor
int waterbuttonPin = 2; // Pin for water button
int sugarbuttonPin = 3; // Pin for sugar button
int waterSensorPin = A1; // Pin for water level sensor
const int buzzerPin = 4; // Pin for buzzer
int dcPin = 5; // Pin for DC motor
int motionSensorPin = A2; // Pin for motion sensor
bool waterbuttonPressed = false; // Flag to track water button press
bool sugarbuttonPressed = false; // Flag to track sugar button press
bool userInfront = false; // Flag to track if user is in front of the machine
bool userAccepted = false; // Flag to track RFID acceptance
bool checkRFID = false; // Flag for RFID card check

// RFID
#include <SPI.h>
#include <MFRC522.h>
#define SS_PIN 10
#define RST_PIN 9
MFRC522 mfrc522(SS_PIN, RST_PIN); // MFRC522 instance


void setup() {

  // Initialize the LCD
  lcd_1.init(); // Initialize LCD display
  lcd_1.backlight(); // Turn on LCD backlight
  
  // Attach servo motors
  waterservo.attach(7); // Attach water servo to pin 7
  teaservo.attach(6); // Attach tea servo to pin 6
  
  // Set pin modes
  pinMode(buzzerPin, OUTPUT); // Set the BUZZER pin as output
  pinMode(dcPin, OUTPUT); // Set the DC motor pin as output
  pinMode(waterbuttonPin, INPUT); // Set the water button pin as input
  Serial.begin(9600); // Initialize serial communication for printing to the serial monitor
  
  // Initialize RFID
  SPI.begin(); // Initialize SPI bus
  mfrc522.PCD_Init(); // Initialize MFRC522
  
  // Display title on LCD screen
  lcd_1.clear(); // Clear the LCD screen
  lcd_1.begin(16, 2); // Set LCD size to 16x2
  lcd_1.print("Smart Tea"); // Print "Smart Tea" on the first line
  lcd_1.setCursor(0, 1); // Move cursor to the second line
  lcd_1.print("Machine"); // Print "Machine" on the second line
  delay(3000); // Delay for 3 seconds
  Serial.println("---------------------Start Machine---------------------"); // Print start message to serial monitor
}


void loop() {
  // Read motion sensor
  int sensorState = digitalRead(motionSensorPin);
  
  // If motion sensor detects user, start welcomeUser() function
  if (sensorState = HIGH && userInfront == false) {
    Serial.println("Motion detected!");
    userInfront = true;
    welcomeUser();
  }

  // Check if the water button is pressed
  if (digitalRead(waterbuttonPin) == HIGH && !waterbuttonPressed) {
    waterbuttonPressed = true; // Set buttonPressed to true to indicate the button has been pressed
    Serial.println("Button pressed. Dispensing water.");
    delay(1000);
    dispenseWater(); // Call the function to dispense water 
    delay(2000);
    dipTeaBag(); // Call function to dispense tea bag in 
    
    // Let the user know sugar is going to dispense 
    Serial.println("Tell User to press sugar button!");
    lcd_1.clear(); // Clear the LCD screen
    lcd_1.setCursor(0, 0);
    lcd_1.print("Press ");
    lcd_1.setCursor(0, 1);
    lcd_1.print("sugar button!");
  }
  
  // Check if the sugar button is pressed
  if (digitalRead(sugarbuttonPin) == HIGH && !sugarbuttonPressed) {
    sugarbuttonPressed = true; // Set buttonPressed to true to indicate the button has been pressed
    Serial.println("Button pressed. Sugar Dispense.");
    sugarDispense(); // Call the function to dispense sugar

    // Prompt user to tap card
    lcd_1.clear();
    lcd_1.setCursor(0, 0);
    lcd_1.print("Tap card");
    lcd_1.setCursor(0, 1);
    lcd_1.print(" ");
  }

  // RFID
  // Look for new cards
  if (!mfrc522.PICC_IsNewCardPresent()) {
    return;
  }
  
  // Select one of the cards
  if (!mfrc522.PICC_ReadCardSerial()) {
    return;
  }
  
  // Show UID on serial monitor
  Serial.print("UID tag :");
  String content= "";
  byte letter;
  for (byte i = 0; i < mfrc522.uid.size; i++) {
    Serial.print(mfrc522.uid.uidByte[i] < 0x10 ? " 0" : " ");
    Serial.print(mfrc522.uid.uidByte[i], HEX);
    content.concat(String(mfrc522.uid.uidByte[i] < 0x10 ? " 0" : " "));
    content.concat(String(mfrc522.uid.uidByte[i], HEX));
  }
  Serial.println();
  content.toUpperCase();

  // Check RFID content
  if (content.substring(1) == "33 2C B6 FC" && checkRFID == true) { // Change here the UID of card/cards or tag/tags that you want to give access
    userAccepted = true;

    Serial.print("Message: ");
    Serial.println("Access Granted");
    lcd_1.clear();
    lcd_1.setCursor(0, 0);
    lcd_1.print("Card accepted!");
    lcd_1.setCursor(0, 1);
    lcd_1.print(" ");
    Serial.println();
    
    delay(5000);

    lcd_1.clear();
    lcd_1.setCursor(0, 0);
    lcd_1.print("Points");
    lcd_1.setCursor(0, 1);
    lcd_1.print("are added!");

    delay(5000);

    lcd_1.clear(); 
    lcd_1.setCursor(0, 0);
    lcd_1.print("Goodbye!");
    lcd_1.setCursor(0, 1);
    lcd_1.print(":)");

    userInfront = false;
  }
  else if (content.substring(1) != "33 2C B6 FC" && checkRFID == true) {
    Serial.println("Access denied");
    lcd_1.clear();
    lcd_1.setCursor(0, 0);
    lcd_1.print("Card");
    lcd_1.setCursor(0, 1);
    lcd_1.print("NOT accepted!!");
  }
}



// Function that runs when user is in front of the motion sensor
void welcomeUser() {
  // Display welcome message on LCD
  lcd_1.begin(16, 2);
  lcd_1.print("Welcome user");
  delay(5000);
  
  // Check water temperature
  checkWaterTemperature();
  delay(2000); // Delay to display the welcome message for 2 seconds
  
  // Prompt user to press button for water
  Serial.println("Ask user if they want water to dispense.");
  lcd_1.clear(); // Clear the LCD screen
  lcd_1.setCursor(0, 0);
  lcd_1.print("For water,");
  lcd_1.setCursor(0, 1);
  lcd_1.print("Press button."); 
}

// Function that checks water temperature
void checkWaterTemperature() {
  // Read DHT Temp 
  Serial.println("Checking water temperature.");
  int chk = DHT.read11(DHT11_PIN);
  Serial.println("Water temperature = ");
  Serial.print(DHT.temperature);
  delay(1000);
  int temp= DHT.temperature;

  // Display temperature
  lcd_1.clear(); // Clear the LCD screen
  lcd_1.setCursor(0, 0);
  lcd_1.print("Checking water ");
  lcd_1.setCursor(0, 1);
  lcd_1.print("temp: ");
  lcd_1.print(temp);
  delay(5000);
  
  // Continuously check temperature until it's at least 20.0°C
  while (temp < 20.0) {
    lcd_1.clear(); // Clear the LCD screen
    lcd_1.setCursor(0, 0);
    lcd_1.print("Water not hot");
    lcd_1.setCursor(0, 1);
    lcd_1.print("temp: ");
    lcd_1.print(temp);
    delay(5000);

    lcd_1.clear(); // Clear the LCD screen
    lcd_1.setCursor(0, 0);
    lcd_1.print("Replace water");
    lcd_1.setCursor(0, 1);
    lcd_1.print("Add hot water");
    delay(10000);

    int chk = DHT.read11(DHT11_PIN);
    Serial.print("Temperature = ");
    Serial.print(DHT.temperature);
    delay(1000);
    int temp= DHT.temperature;
  }

  // Water temperature is at least 20.0°C
  lcd_1.clear(); // Clear the LCD screen
  lcd_1.setCursor(0, 0);
  lcd_1.print("Water is perfect");
  lcd_1.setCursor(0, 1);
  lcd_1.print("temp: ");
  lcd_1.print(temp);
  delay(5000);
}

// Function that dispenses water
void dispenseWater() {
  Serial.println("Water servo rotating to 90 degrees.");
  
  // Display on LCD that water is being dispensed 
  lcd_1.clear();
  lcd_1.setCursor(0, 0);
  lcd_1.print("Water is");
  lcd_1.setCursor(0, 1);
  lcd_1.print("dispensing now");  
  
  // Turn servo motor for water to pass through
  delay(500); // Delay for 0.5 seconds
  
  int waterLevel = readWaterLevel();  // Assuming readWaterLevel() is a function to read the water level from the sensor
    
  // Print updated water level
  Serial.println("Updated Water Level: " + String(waterLevel));
  
  // Continue dispensing water until water level reaches 0
  while(readWaterLevel()>250) {
    for (pos2 = 0; pos2 <= 30; pos2 += 1) { // goes from 0 degrees to 180 degrees
      // in steps of 1 degree
      waterservo.write(pos2);              // tell servo to go to position in variable 'pos'
      delay(15);                       // waits 15ms for the servo to reach the position
    }
    for (pos2 = 30; pos2 >= 0; pos2 -= 1) { // goes from 180 degrees to 0 degrees
      waterservo.write(pos2);              // tell servo to go to position in variable 'pos'
      delay(15);                       // waits 15ms for the servo to reach the position   
    }
    count1++;
    Serial.println(count1);
    
    // Read updated water level from the sensor
    int waterLevel = readWaterLevel();  // Assuming readWaterLevel() is a function to read the water level from the sensor
    
    // Print updated water level
    Serial.println("Updated Water Level: " + String(waterLevel));
    count1++;
  } 
  
  // Display on LCD that water dispensing is done
  lcd_1.clear();
  lcd_1.setCursor(0, 0);
  lcd_1.print("Water is done");
  lcd_1.setCursor(0, 1);
  lcd_1.print("");
  delay(5000);
  lcd_1.clear();
}

// Function to read water level from sensor 
int readWaterLevel() {
  return analogRead(A1);         // send current reading
}

// Function that dips tea bag in
void dipTeaBag() {
  // Display on LCD that is tea bag is being dispensed 
  lcd_1.clear();
  lcd_1.setCursor(0, 0);
  lcd_1.print("Tea bag is");
  lcd_1.setCursor(0, 1);
  lcd_1.print("dispensing now");  

  // Dip the tea bag into the cup by rotating the servo to 90 degrees
  // teaservo.write(180);
  Serial.println("Tea servo dipping tea bag.");
  delay(500); // Delay for 0.5 seconds

  while(count < 10) {
    for (pos = 60; pos <= 100; pos += 1) { // goes from 0 degrees to 180 degrees
      // in steps of 1 degree
      teaservo.write(pos);              // tell servo to go to position in variable 'pos'
      delay(15);                       // waits 15ms for the servo to reach the position
    }
  
    for (pos = 100; pos >= 60; pos -= 1) { // goes from 180 degrees to 0 degrees
      teaservo.write(pos);              // tell servo to go to position in variable 'pos'
      delay(15);                       // waits 15ms for the servo to reach the position   
    }
    count++;
  }

  // Display on LCD that is tea bag is being dispensed 
  lcd_1.clear();
  lcd_1.setCursor(0, 0);
  lcd_1.print("Tea is brewing");
  lcd_1.setCursor(0, 1);
  
  // Call function to display brewing time while tea bag is dipped in 
  displayBrewingTimer();
    
  // After the brewing time is over, lift the tea bag out of the cup
  teaservo.write(90);
  Serial.println("Tea servo lifting tea bag");
  
  // Display on LCD that is tea bag is done brewing 
  lcd_1.clear();
  lcd_1.setCursor(0, 0);
  lcd_1.print("Tea is done");
  
  // Buzzer goes off since Tea is done brewing
  Serial.println("Buzzer turns on to indicate buzzer tea is done brewing");
  tone(buzzerPin, 3000); // Send 1KHz sound signal...
  delay(5000);        // ...for 1 sec
  noTone(buzzerPin);     // Stop sound...
  lcd_1.clear();
}

// This function will display the timer for brewing
void displayBrewingTimer() {
  // Calculate the end time of brewing (10 seconds from now)
  unsigned long endTime = millis() + 10000; // 10 seconds in milliseconds
  unsigned long currentTime = millis();
  int remainingTime = 10; // Initial value in seconds
  
  while (currentTime < endTime) {
    // Update remaining time every second
    lcd_1.setCursor(0, 1); // Set cursor to the position where the timer will be displayed
    if (remainingTime < 10) {
        lcd_1.print("0"); // Print leading zero if remaining time is less than 10
    }
    lcd_1.print(remainingTime); // Print remaining time
    delay(1000); // Delay for 1 second
    currentTime = millis(); // Update current time
    remainingTime = (endTime - currentTime) / 1000; // Calculate remaining time in seconds
    lcd_1.setCursor(0, 1);
    lcd_1.print(" "); // Clear the previous number
  } 
}

// Function that will dispense sugar packet
void sugarDispense() {
  lcd_1.clear(); // Clear the LCD screen
  lcd_1.setCursor(0, 0);
  lcd_1.print("Dispensing");
  lcd_1.setCursor(0, 1);
  lcd_1.print("sugar");
  Serial.println("DC motor is running to dispense the sugar");
  analogWrite(dcPin, 100);
  delay(10000); // Adjust for how long it takes for sugar to finish pushing
  analogWrite(dcPin, 0);
  lcd_1.clear();
  checkRFID = true;
  teaDone();
}

// Function when tea is done
void teaDone() {
  lcd_1.clear(); // Clear the LCD screen
  lcd_1.setCursor(0, 0);
  lcd_1.print("Tea is");
  lcd_1.setCursor(0, 1);
  lcd_1.print("Done!");

  Serial.println("Buzzer turns on to indicate buzzer tea is done");
  tone(buzzerPin, 3000); // Send 1KHz sound signal...
  delay(5000);        // ...for 1 sec
  noTone(buzzerPin);     // Stop sound...
  
  lcd_1.clear(); // Clear the LCD screen
  lcd_1.setCursor(0, 0);
  lcd_1.print("Perfect Tea!");
  lcd_1.setCursor(0, 1);
  lcd_1.print("Thank you!");
  delay(5000);

  lcd_1.clear(); // Clear the LCD screen
  lcd_1.setCursor(0, 0);
  lcd_1.print("Scan Card!");
  lcd_1.setCursor(0, 1);
  lcd_1.print("For Points!!");
  delay(5000);
}
